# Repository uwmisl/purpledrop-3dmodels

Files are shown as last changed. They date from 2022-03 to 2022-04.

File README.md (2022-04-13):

PurpleDrop 3D Models
=============================

This is a collection of 3D-printable parts which can be helpful for building
and using a PurpleDrop.

## Models

### Tape Jig for 50mm top plate

Fixture to help with alignment of copper tape on glass edge.

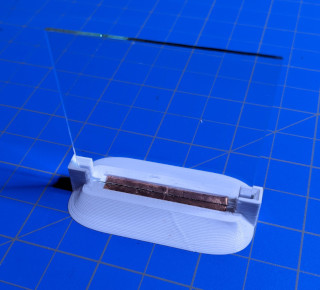
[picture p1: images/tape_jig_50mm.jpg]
Tape Jig 50mm Tape Jig, 50mm


[tapejig_50mm.stl](/tape_jigs/tapejig_50mm.stl)

### Tape Jig for 75mm top plate

The above, but for 75mm glass edges.

[tapejig_75mm.stl](/tape_jigs/tapejig_75mm.stl)

### Overhead Camera Stand for Raspberry PI camera

Simple stand for holding a raspberry pi v2 camera over the purpledrop. 

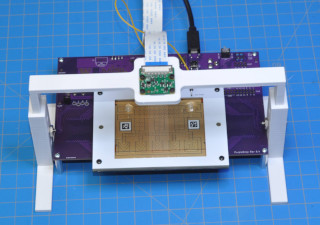
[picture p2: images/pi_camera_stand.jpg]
Pi Camera Stand


You'll need some hardware to assemble: 
    - Small screws/nuts for attaching the camera: M1.8, #1-72, or smaller.
    - Larger screws/nuts for setting the height: M3 or #6 screws work well here. Length around 18mm.

STL Files:
- [pi_camera_stand_bottom.stl](pi_camera_stand/pi_camera_stand_bottom.stl) (Need two)
- [pi_camera_stand_top.stl](pi_camera_stand/pi_camera_stand_top.stl)

### Holder for 50x75mm glass plate

Useful for short term storage, or while working on a glass plate. It allows
the plate to be set down while minimizing physical contact to only the corners.

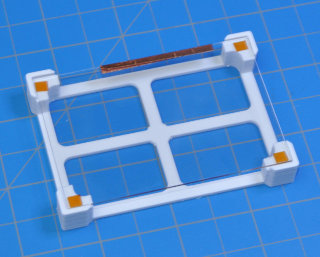
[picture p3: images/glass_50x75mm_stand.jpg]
Glass holder


[glass_stand_50x75.stl](holders/glass_stand_50x75.stl)

### Spin coater chuck

There are several parts available for spin-coating top plates and dielectric
films. They can be found in the [spin_coating sub-directory](spin_coating/).

### Storage box for dielectric frames

Hinged box to store/transport 100x75mm dielectric frames. If creating these in batches,
it's useful to have a safe place to store them to keep safe from accidental contact
and dust.

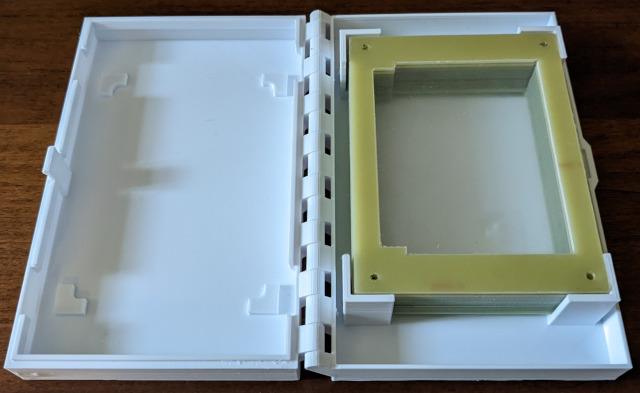
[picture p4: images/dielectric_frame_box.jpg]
Dielectric Frame Box


[dielectric_frame_box.stl](storage/dielectric_frame_box.stl)

[dielectric_frame_box.f3d](storage/dielectric_frame_box.f3d)

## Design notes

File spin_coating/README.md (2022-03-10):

Spin Coater Chuck
=================

Building surfaces for the PurpleDrop requires spin-coating a hydrophobic
coating. Many spin-coaters come with a vacuum chuck for holding the substrate,
and this works well for glass plates. However, it does
not work so well for the dielectric film, as it is not as rigid. Additionally,
commercial spin coaters are expensive and may not be available, but it
it possible to [build one](https://github.com/mcbridejc/spincoater) cheaply
from hobby motors.

This chuck system allows for quick release of 100x74mm dielectric frame (the
standard size used by all MISL electrode boards), 50x50mm glass plates, and
50x75mm glass plates. It is designed to be attached to 
[this servo city motor hub](https://www.servocity.com/0-125-0-770-set-screw-hub/)
but an adapter is also available to use this fixture on a standard vacuum chuck
spin coater.

## The Main Chuck

To build the chuck, you will need to print these components, and you will
need M2 threaded heat inserts (like [these](https://www.mcmaster.com/94459A110/))
plus M2x5mm screws (like [these](https://www.mcmaster.com/92000A012/)) to
attach the locking arms.

The part can be printed on an FDM 3D printer with PLA filament. The heat inserts
are then melted into the holes in the part -- special "heat-set insert tips" for 
soldering irons exist for this, although it is possible to insert them using a
standard conical soldering iron tip. If you've never used heat inserts, consider
printing a small test part with some 3.2mm diameter holes and practicing on that
first.

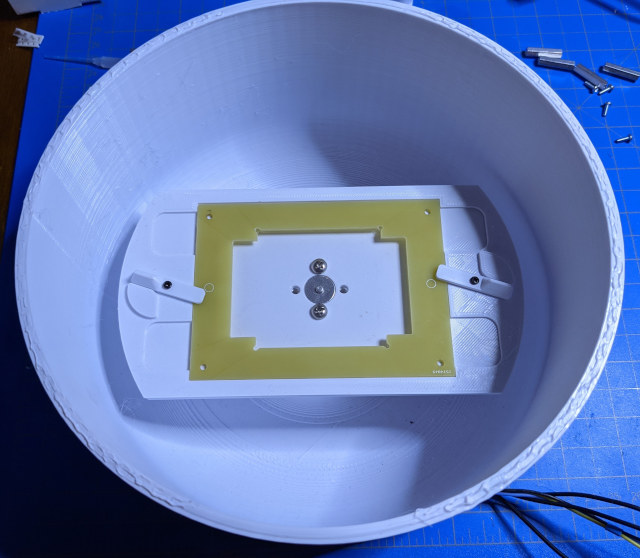
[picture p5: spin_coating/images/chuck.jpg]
Spincoater Chuck


[spincoater_100x74_chuck.stl](spincoater_100x74_chuck.stl) - The main part

[spincoater_chuck_lock_lever.stl](spincoater_chuck_lock_lever.stl) - Two of these attach to secure the part in place

## Glass adapters

For coating glass top plates, there are two adapters (one for 50x50mm, and one
for 50x75mm glass) which can be quickly attached to the main chuck. Flexure in
the arms is used to secure the glass plate.

Both adapters use a common base. To build the adapter the base and glass chuck
should be printed, and they can then be glued together with CA glue.

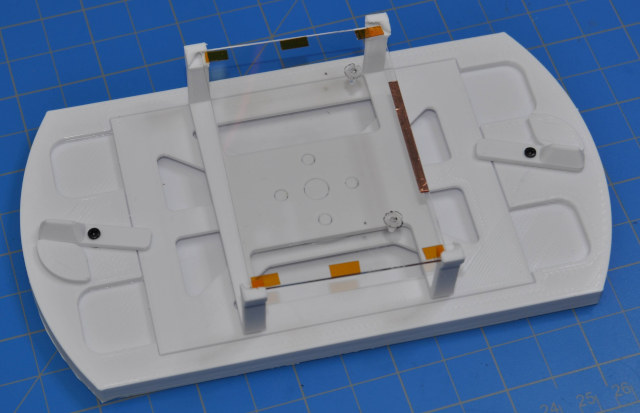
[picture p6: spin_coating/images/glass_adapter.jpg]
Glass Adapter


[spincoater_chuck_adapter_base.stl](spincoater_chuck_adapter_base.stl)

[spincoater_glass_chuck_50x75.stl](spincoater_glass_chuck_50x75.stl)

[spincoater_glass_chuck_50x50.stl](spincoater_glass_chuck_50x50.stl)

## Vacuum Chuck Adapter

The vacuum adapter is two parts, which glue together (CA glue recommended)
and then glue onto the main chuck component.
It is intended to fit on a 40mm diameter vacuum chuck.
Make sure that you get a good seal -- i.e. you can pull a strong vacuum -- 
with the face. I have found it to work, but this may depend on the 
surface quality of your 3D printed part, as well as the stiffness of the seal
on the chuck. If you find it leaks, you may be able to glue on a small laser
cut piece of acrylic or other plastic to provide a smooth surface to seal.

[spincoater_chuck_vacuum_adapter_A.stl](spincoater_chuck_vacuum_adapter_A.stl)
[spincoater_chuck_vacuum_adapter_B.stl](spincoater_chuck_vacuum_adapter_B.stl)

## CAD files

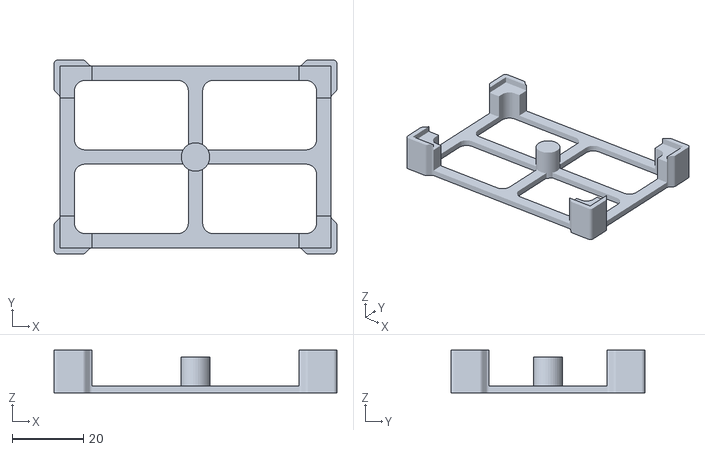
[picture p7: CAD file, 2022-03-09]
holders/glass_stand_50x75.stl
79.4 x 54.4 x 12.0

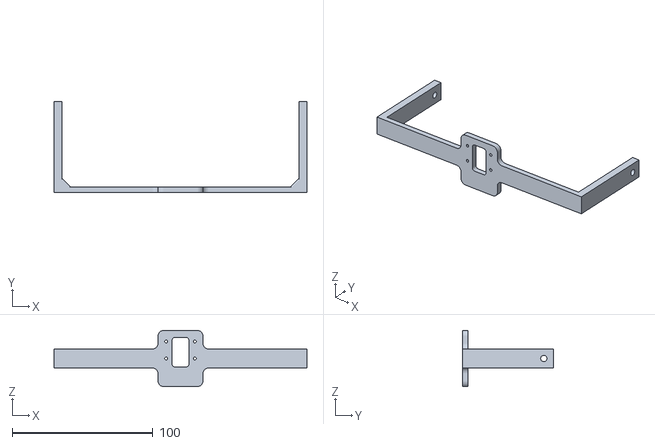
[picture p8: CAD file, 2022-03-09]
pi_camera_stand/pi_camera_stand_top.stl
180.0 x 65.0 x 40.0

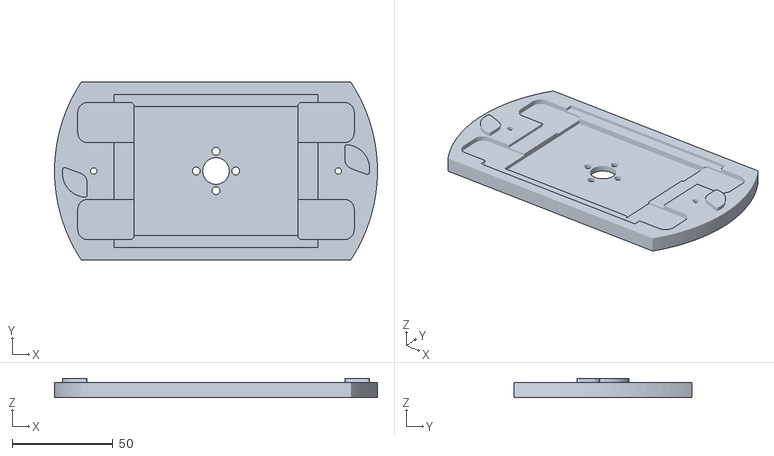
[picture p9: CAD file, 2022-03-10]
spin_coating/spincoater_100x74_chuck.stl
160.0 x 88.0 x 9.60

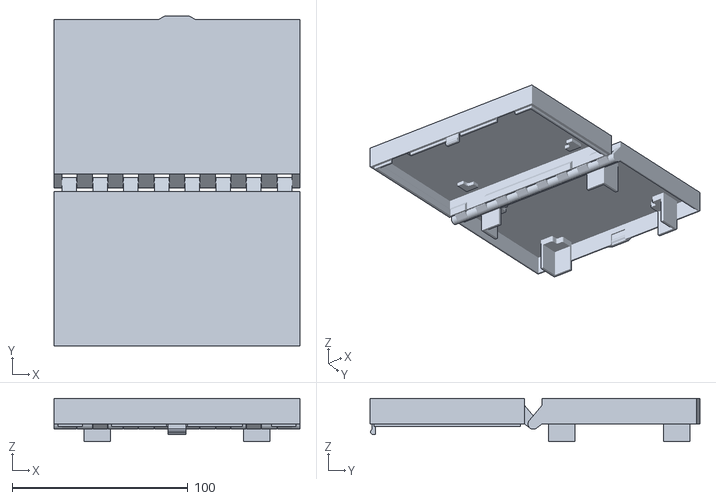
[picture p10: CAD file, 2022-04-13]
storage/dielectric_frame_box.stl
140.0 x 188.0 x 24.5

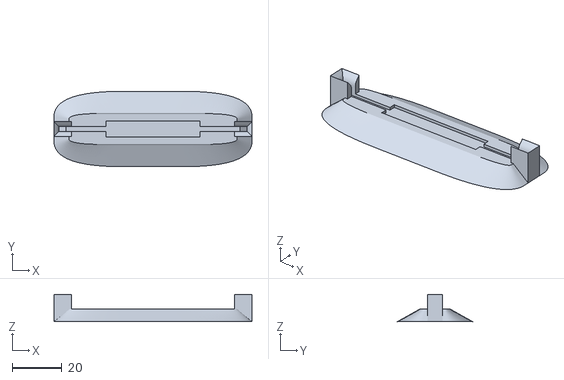
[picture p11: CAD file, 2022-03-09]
tapejigs/tapejig_75mm.stl
80.0 x 30.4 x 11.0

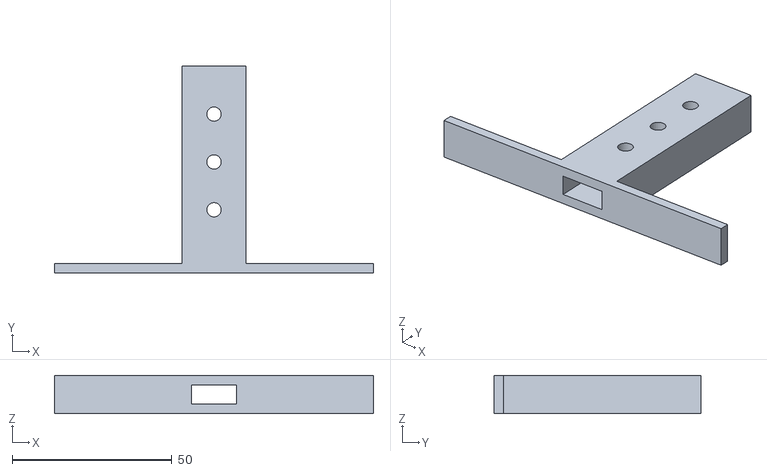
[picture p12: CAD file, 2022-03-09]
pi_camera_stand/pi_camera_stand_bottom.stl
100.0 x 65.0 x 12.0

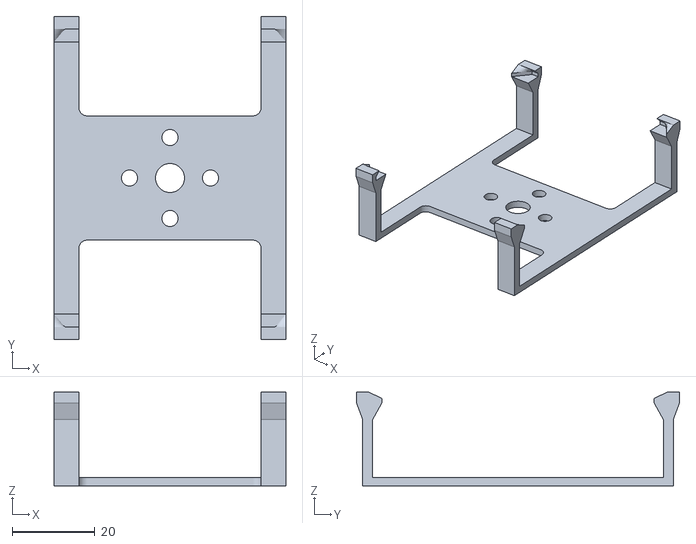
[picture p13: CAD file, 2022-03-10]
spin_coating/spincoater_glass_chuck_50x75.stl
56.0 x 78.0 x 22.6

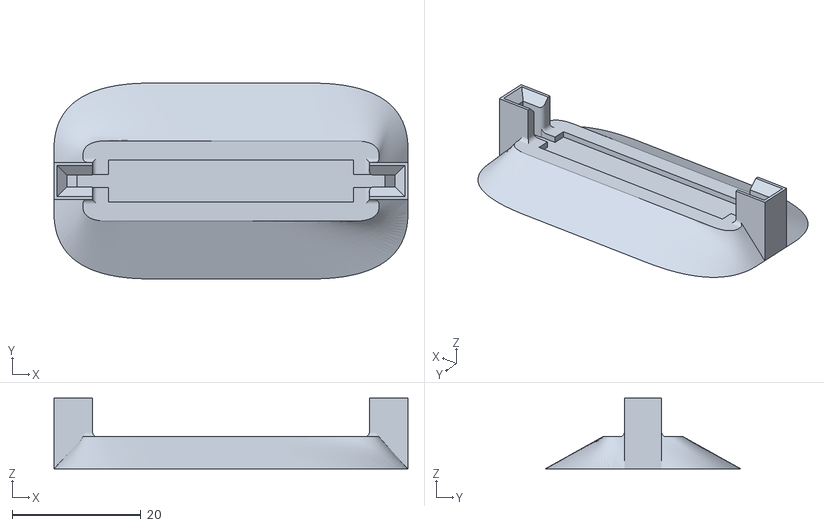
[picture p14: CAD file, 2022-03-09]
tapejigs/tapejig_50mm.stl
55.0 x 30.4 x 11.0

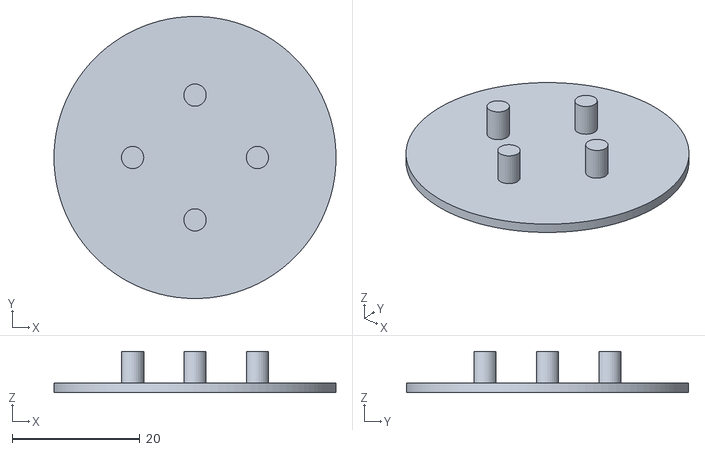
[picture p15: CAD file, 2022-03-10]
spin_coating/spincoater_chuck_vacuum_adapter_B.stl
44.2 x 44.2 x 6.50

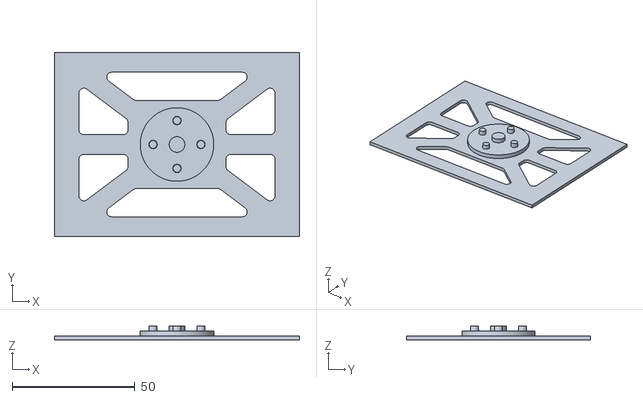
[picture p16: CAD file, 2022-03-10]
spin_coating/spincoater_chuck_adapter_base.stl
100.0 x 75.0 x 5.60

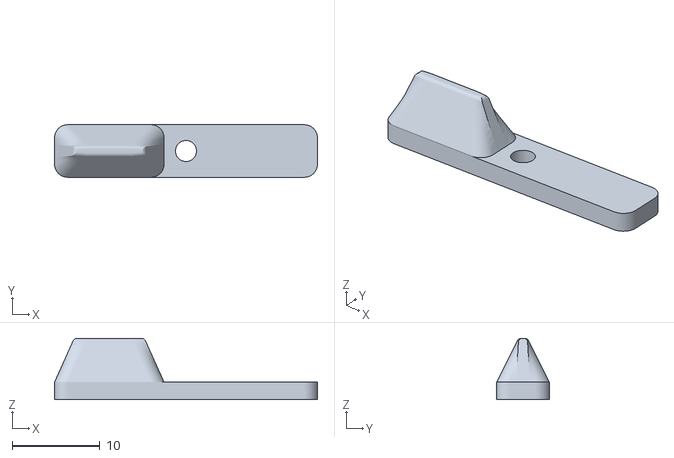
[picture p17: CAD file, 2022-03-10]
spin_coating/spincoater_chuck_lock_lever.stl
30.0 x 6.00 x 7.00

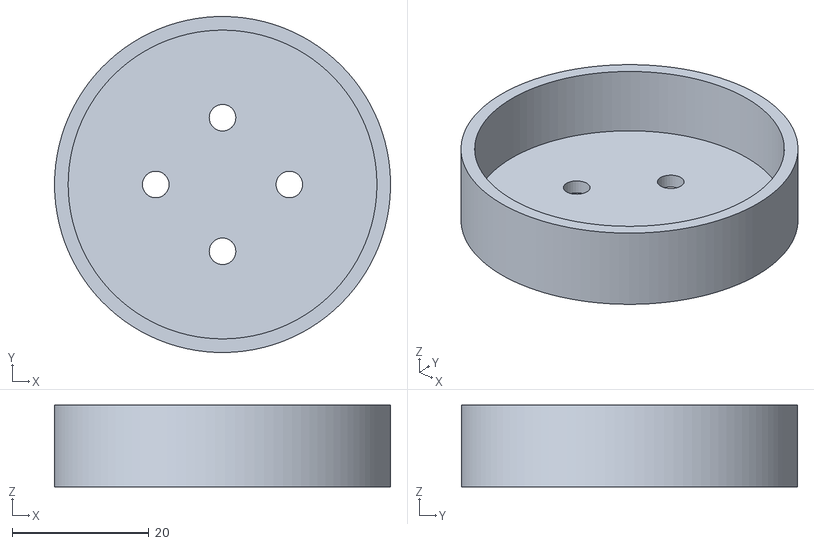
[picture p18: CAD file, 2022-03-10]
spin_coating/spincoater_chuck_vacuum_adapter_A.stl
49.2 x 49.2 x 12.0

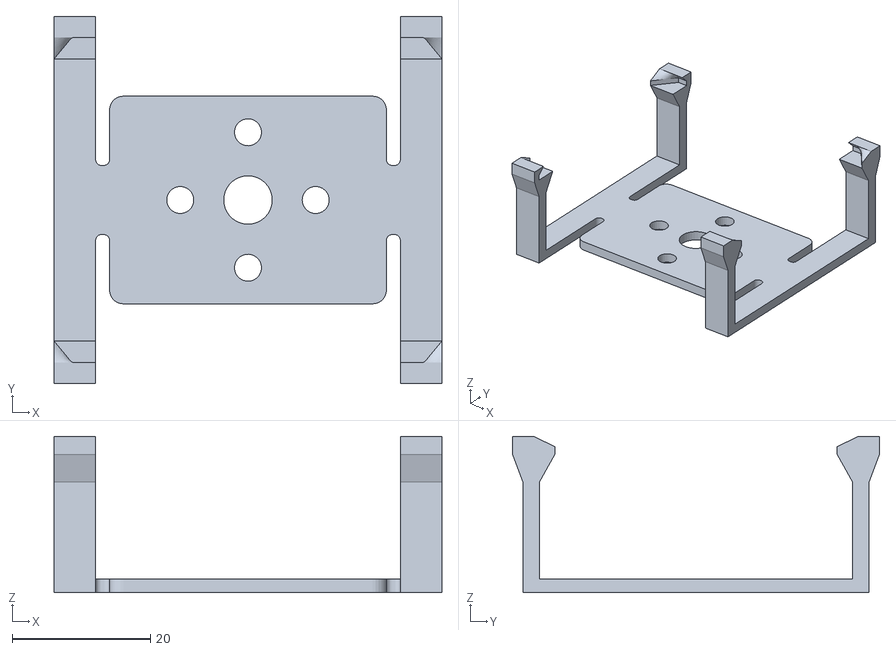
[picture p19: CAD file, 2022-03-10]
spin_coating/spincoater_glass_chuck_50x50.stl
56.0 x 53.0 x 22.6

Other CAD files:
storage/dielectric_frame_box.f3d

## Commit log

2022-03-10 Add spin coater parts
    [spincoater_100x74_chuck.stl, spincoater_chuck_adapter_base.stl, spincoater_chuck_lock_lever.stl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]
2022-04-13 Add dielectric frame box
    [dielectric_frame_box.f3d, dielectric_frame_box.stl]
